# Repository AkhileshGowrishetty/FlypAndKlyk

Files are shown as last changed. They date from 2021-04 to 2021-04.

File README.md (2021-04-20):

# FlypAndKlyk
Self-sustaining system used to call office staff on demand using nRF24L01 and ATMEGA328P.

# Images
<kbd>Receiver</kbd><kbd>Transmitter</kbd>

<kbd>Receiver_PCB</kbd><kbd>Receiver_TopSide</kbd>

<kbd>Transmitter_withBatteryHolder</kbd><kbd>Transmitter_PCB</kbd>

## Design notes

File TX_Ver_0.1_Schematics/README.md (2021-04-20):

The PCB design is just for documentation. The dimensions of PCB and 3D case are different.

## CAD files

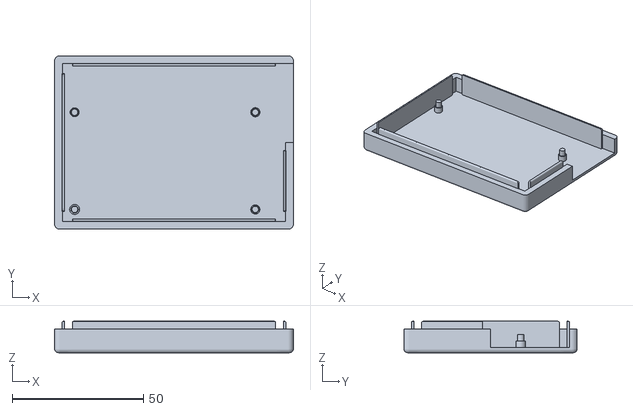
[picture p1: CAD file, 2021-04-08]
3D Cases/RX_Ver_0.1/RX_Ver_0.1_Bottom.stl
91.0 x 66.0 x 12.0

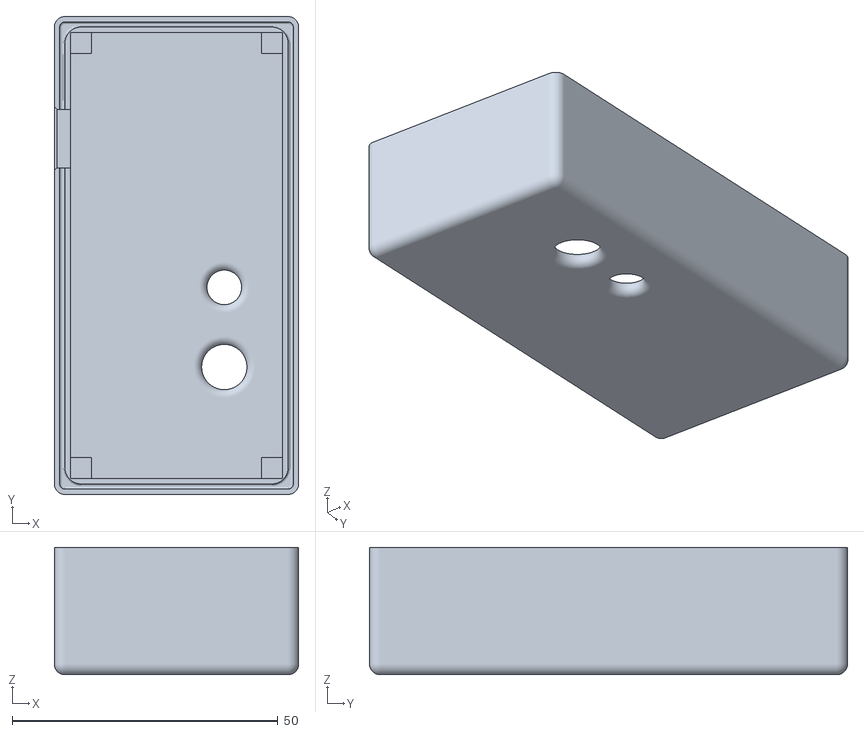
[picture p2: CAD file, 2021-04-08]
3D Cases/TX_Ver_0.1/TX_Ver_0.1_Top.stl
46.0 x 90.0 x 24.0

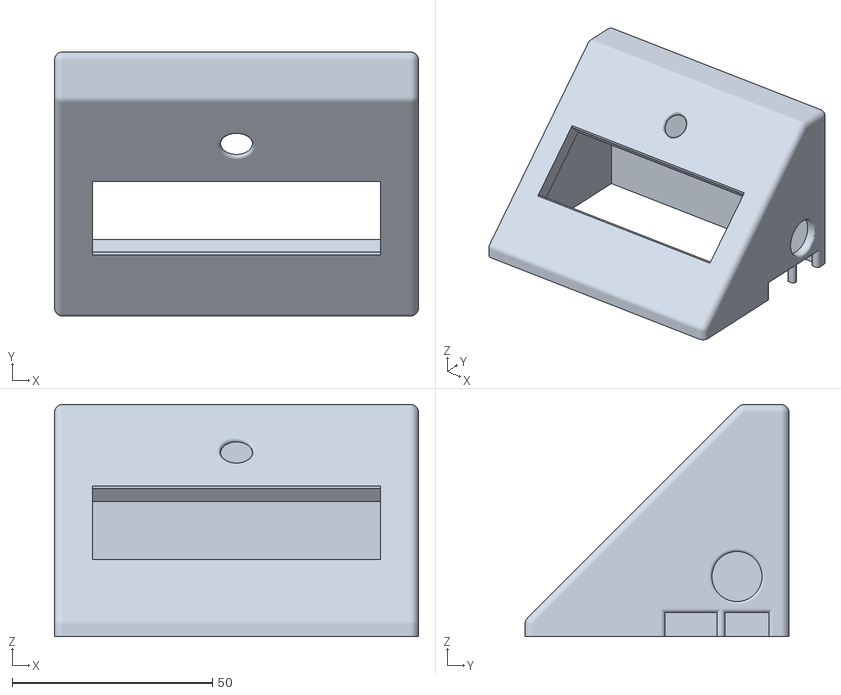
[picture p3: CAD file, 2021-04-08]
3D Cases/RX_Ver_0.1/RX_Ver_0.1_Top.stl
91.0 x 66.0 x 58.0

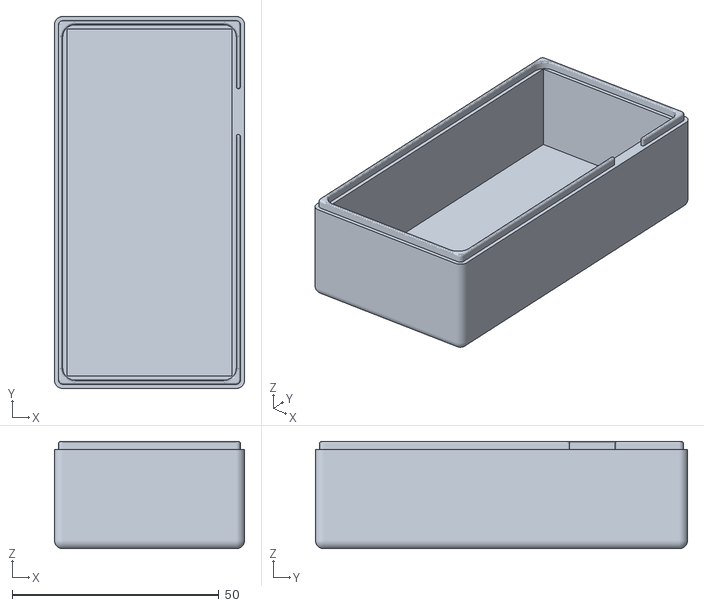
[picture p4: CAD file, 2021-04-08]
3D Cases/TX_Ver_0.1/TX_Ver_0.1_Bottom.stl
46.0 x 90.0 x 26.0

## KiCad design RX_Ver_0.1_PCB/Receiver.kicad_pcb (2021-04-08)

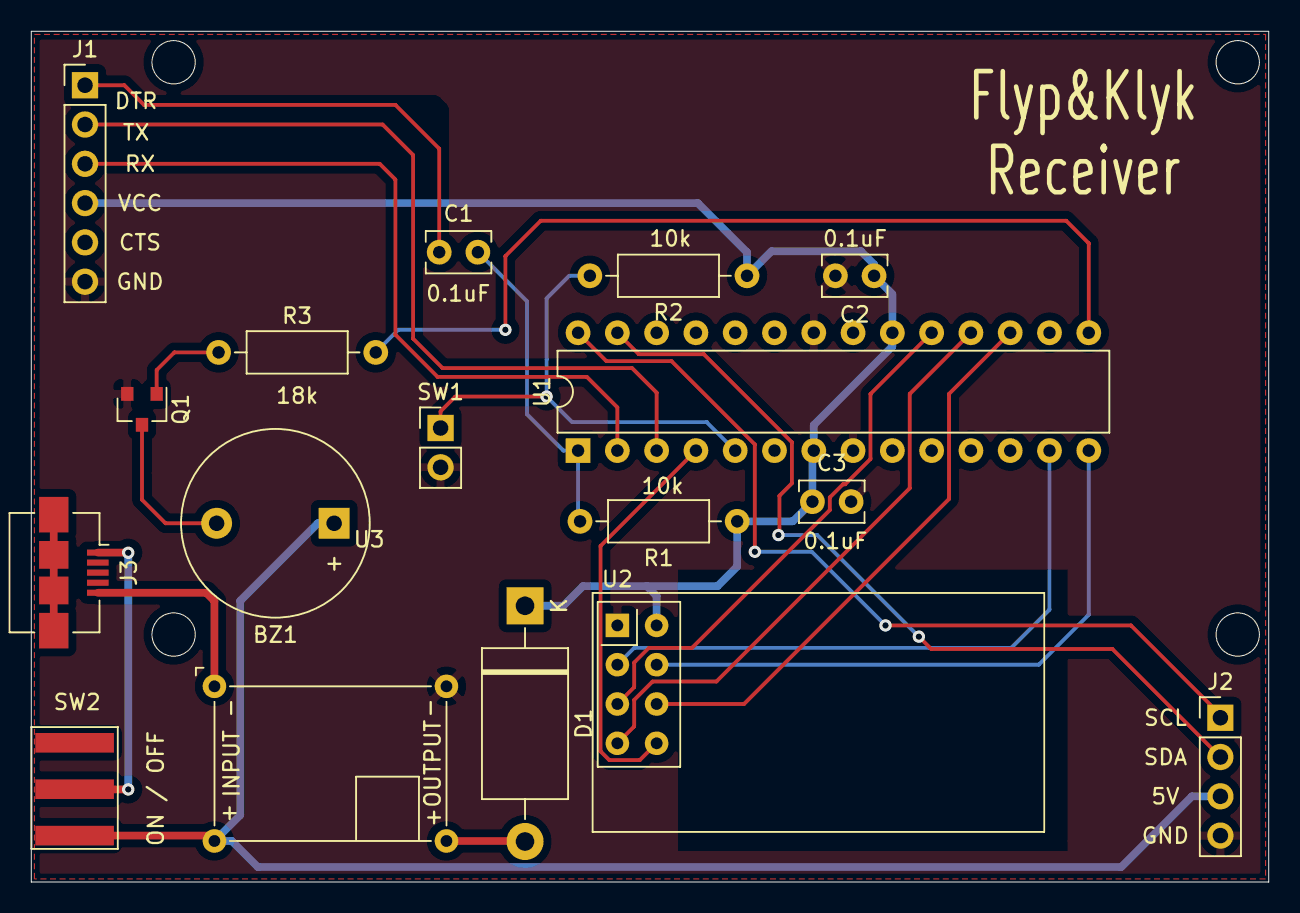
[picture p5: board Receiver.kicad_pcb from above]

Board: 2 copper layers, 80.0 x 55.0 mm, 17 parts (0 on the bottom side), 22 nets.

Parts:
BZ1: Buzzer; Buzzer_12x9.5RM7.6
C1, C2, C3: 0.1uF; C_Rect_L4.0mm_W2.5mm_P2.50mm
D1: DIODE; D_DO-27_P15.24mm_Horizontal
J1: Conn_01x06; PinHeader_1x06_P2.54mm_Vertical
J2: Conn_01x04; PinHeader_1x04_P2.54mm_Vertical
J3: USB_B_Micro; USB_Micro-B_Amphenol_10104110_Horizontal
Q1: BC847; SOT-23
R1, R2: 10k; R_Axial_DIN0207_L6.3mm_D2.5mm_P10.16mm_Horizontal
R3: 18k; R_Axial_DIN0207_L6.3mm_D2.5mm_P10.16mm_Horizontal
SW1: SW_Push; PinHeader_1x02_P2.54mm_Vertical
SW2: SW_DPDT_x2; Slide_Switch
U1: ATmega328P-PU; DIP-28_W7.62mm
U2: NRF24L01_Breakout; nRF24L01_Breakout
U3: MP1584_BuckConverter_3A; MP1584_3A_Buck

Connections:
+5V: BZ1.1, J2.3, SW2.3, U3.1
BUZZER: R3.2, U1.15
CE: U1.13, U2.3
CSN: U1.14, U2.4
DTR: C1.2, R1.2, U1.1
DTR_FTDI: C1.1, J1.1
GND: C2.2, C3.2, J1.6, J2.4, Q1.2, SW1.2, U1.8, U1.22, U2.1, U3.4
IRQ: U1.4, U2.8
MISO: U1.18, U2.7
MOSI: U1.17, U2.6
unnamed: BZ1.2, Q1.3
unnamed: D1.2, U3.3
unnamed: J3.1, SW2.2
unnamed: J3.5, U3.2
unnamed: Q1.1, R3.1
unnamed: R2.2, SW1.1, U1.5
RX: J1.3, U1.2
SCK: U1.19, U2.5
SCL: J2.1, U1.28
SDA: J2.2, U1.27
TX: J1.2, U1.3
VCC: C2.1, C3.1, D1.1, J1.4, R1.1, R2.1, U1.7, U1.20, U2.2

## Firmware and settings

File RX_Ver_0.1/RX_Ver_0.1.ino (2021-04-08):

/*--------------------
	Flyp & Klyk.
	
	Self-sustaining system used to call office staff on demand.
	
	This code is for the button or transmitter. 
	
	Dependencies:
	- RF24                 (https://github.com/nRF24/RF24)
	- RF24Network          (https://github.com/nRF24/RF24Network)
	- LiquidCrystal_I2C    (https://github.com/fmalpartida/New-LiquidCrystal)
  - TaskScheduler        (https://github.com/arkhipenko/TaskScheduler)
  
	*** Edit variables present in file: "variables.h" ***

  --------------------*/
  
#include "includes.h"   // Header file for libraries and variables.

void setup() {

  pinMode(button_pin, INPUT);
  
  pinMode(buzzer_pin, OUTPUT);
  
  setup_radio();

  setup_lcd("TEXT", 2000);    // Setup of LCD with Custom text ( Length of text must be less than or equal to 16 characters).
  
}

void loop() {
  ts.execute();   

  check_message();
  
  if ( disable_message_update ) {
    message_update.disable();
    disable_message_update = false;
    
    uint16_t to_node = 00;
    RF24NetworkHeader header(to_node, 'A');
    bool send_ack = true;
    
    if ( node_address == 00 ) {
      network.multicast(header, &send_ack, sizeof(send_ack), 1);
    }
    else {
      network.multicast(header, &send_ack, sizeof(send_ack), 1);
      network.write(header, &send_ack, sizeof(send_ack));
    }
    
  }
}

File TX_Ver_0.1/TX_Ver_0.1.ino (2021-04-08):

/*--------------------
	Flyp & Klyk.
	
	Self-sustaining system used to call office staff on demand.
	
	This code is for the button or transmitter. 
	
	Dependencies:
	- RF24                    (https://github.com/nRF24/RF24)
	- RF24Network             (https://github.com/nRF24/RF24Network)
	- BatteryVoltageReader    (https://github.com/RalphBacon/Arduino-Battery-Monitor)

	*** Edit variables present in file: "variables.h" ***

  --------------------*/

#include "includes.h"   // Header file for libraries and variables

void setup() {
  
  BVR.begin();
  SPI.begin();    
  radio.begin();    
  radio.setPALevel(RF24_PA_HIGH);   
  network.begin(node_address);
  network.setup_watchdog(wdt_2s);   // Setup of watchdog for sleep time of 2 seconds.
  network.multicastLevel(2);        // Setting multicastLevel as 2 for transmitters as to not wake in case of multicast.
  network.multicastRelay = true;    // Enabling multicast relay.

  attachInterrupt(digitalPinToInterrupt(button_pin), button_ISR, FALLING);    // Setting up interrupt (falling) on digital pin 3. 

  pinMode(led_pin, OUTPUT);   // Setting up LED for indication.

  // Setting up message/payload to be sent.
  strlcpy(message.buffer, text, sizeof(message.buffer));
  message.freq = frequency;   
  message.bat_volt = BVR.readVCC();
  
}

void loop() {
  network.update();   // Needs to be called frequently to keep the network active.

  if( button_pressed ) {  
    button_pressed = false;  
    message.bat_volt = BVR.readVCC();   // Updating battery voltage before sending.

    bool success = send_C();    // To send message to display.
    blink_led(success);     // To show status of transmission.
    
    // Putting transmitter to sleep to reduce power consumption.
    if ( millis() - sleep_timer > awake_time ) {
      sleep_timer = millis();
      delay(50);
      radio.stopListening();
      network.sleepNode(5, NRF_interrupt_pin);      // sleepNode(cycles, interrupt-pin)
    }
  }
}

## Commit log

2021-04-08 RX PCB Schematics and Design
    [Receiver.kicad_pcb, Receiver.sch]
2021-04-08 3D Cases & TX PCB
    [RX_Ver_0.1_Bottom.stl, RX_Ver_0.1_Top.stl, TX_Ver_0.1_Bottom.stl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]
2021-04-08 Moved TX 3D Case location
    [TX_Ver_0.1_Bottom.stl, TX_Ver_0.1_Top.stl]
2021-04-20 Update about PCB Design and 3D case
